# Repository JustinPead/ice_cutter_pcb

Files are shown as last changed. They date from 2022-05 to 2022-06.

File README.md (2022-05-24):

# ice_cutter_pcb
The PCB for the ice cutter project

This is a component for the greater project of an automated Ice cutting rig

The PCB is responsible for providing the power, receiving the power setting (potentiometer) and providing information on the current status (7 Seg and LEDS)
It has an onboard temperature sensor to determine the initial conditions for the ice rig.

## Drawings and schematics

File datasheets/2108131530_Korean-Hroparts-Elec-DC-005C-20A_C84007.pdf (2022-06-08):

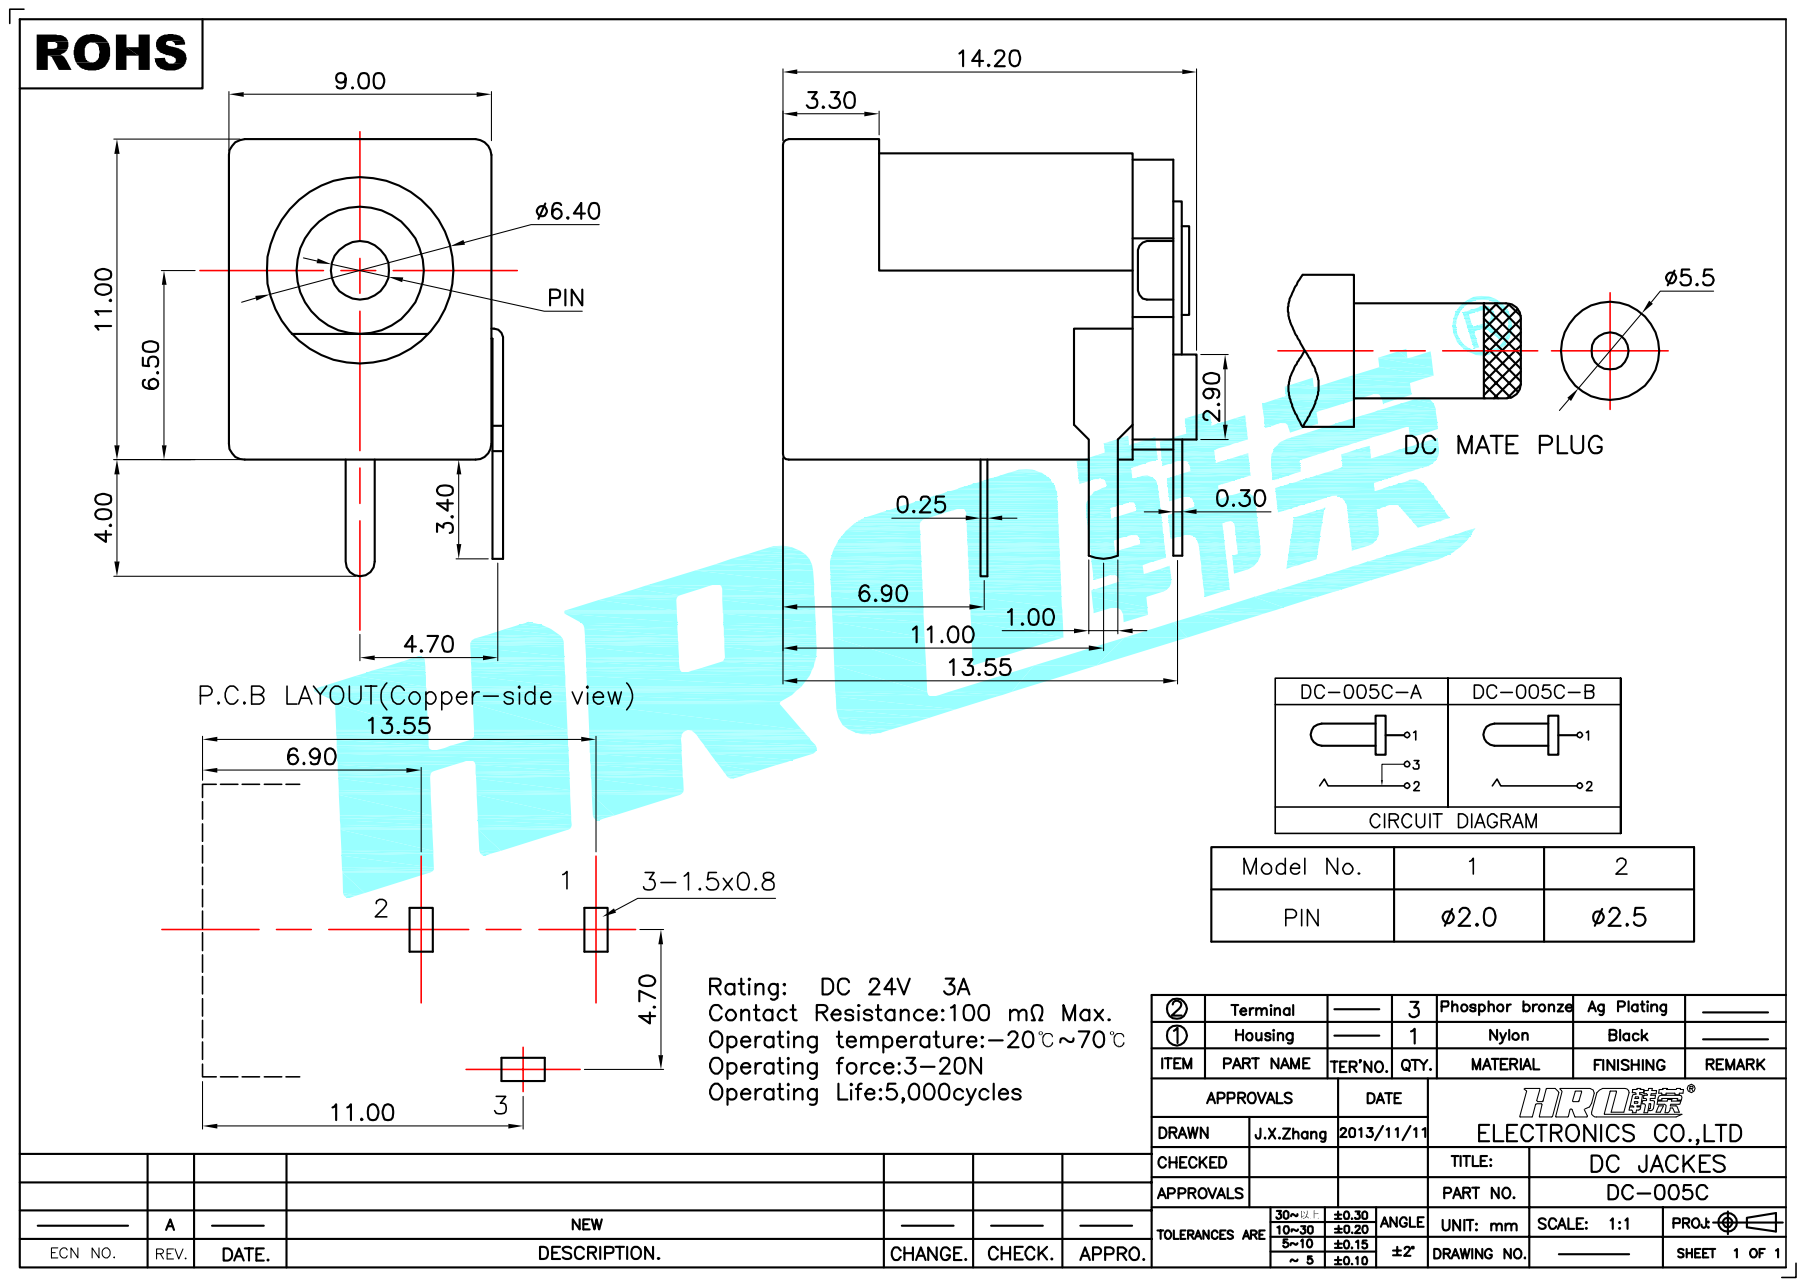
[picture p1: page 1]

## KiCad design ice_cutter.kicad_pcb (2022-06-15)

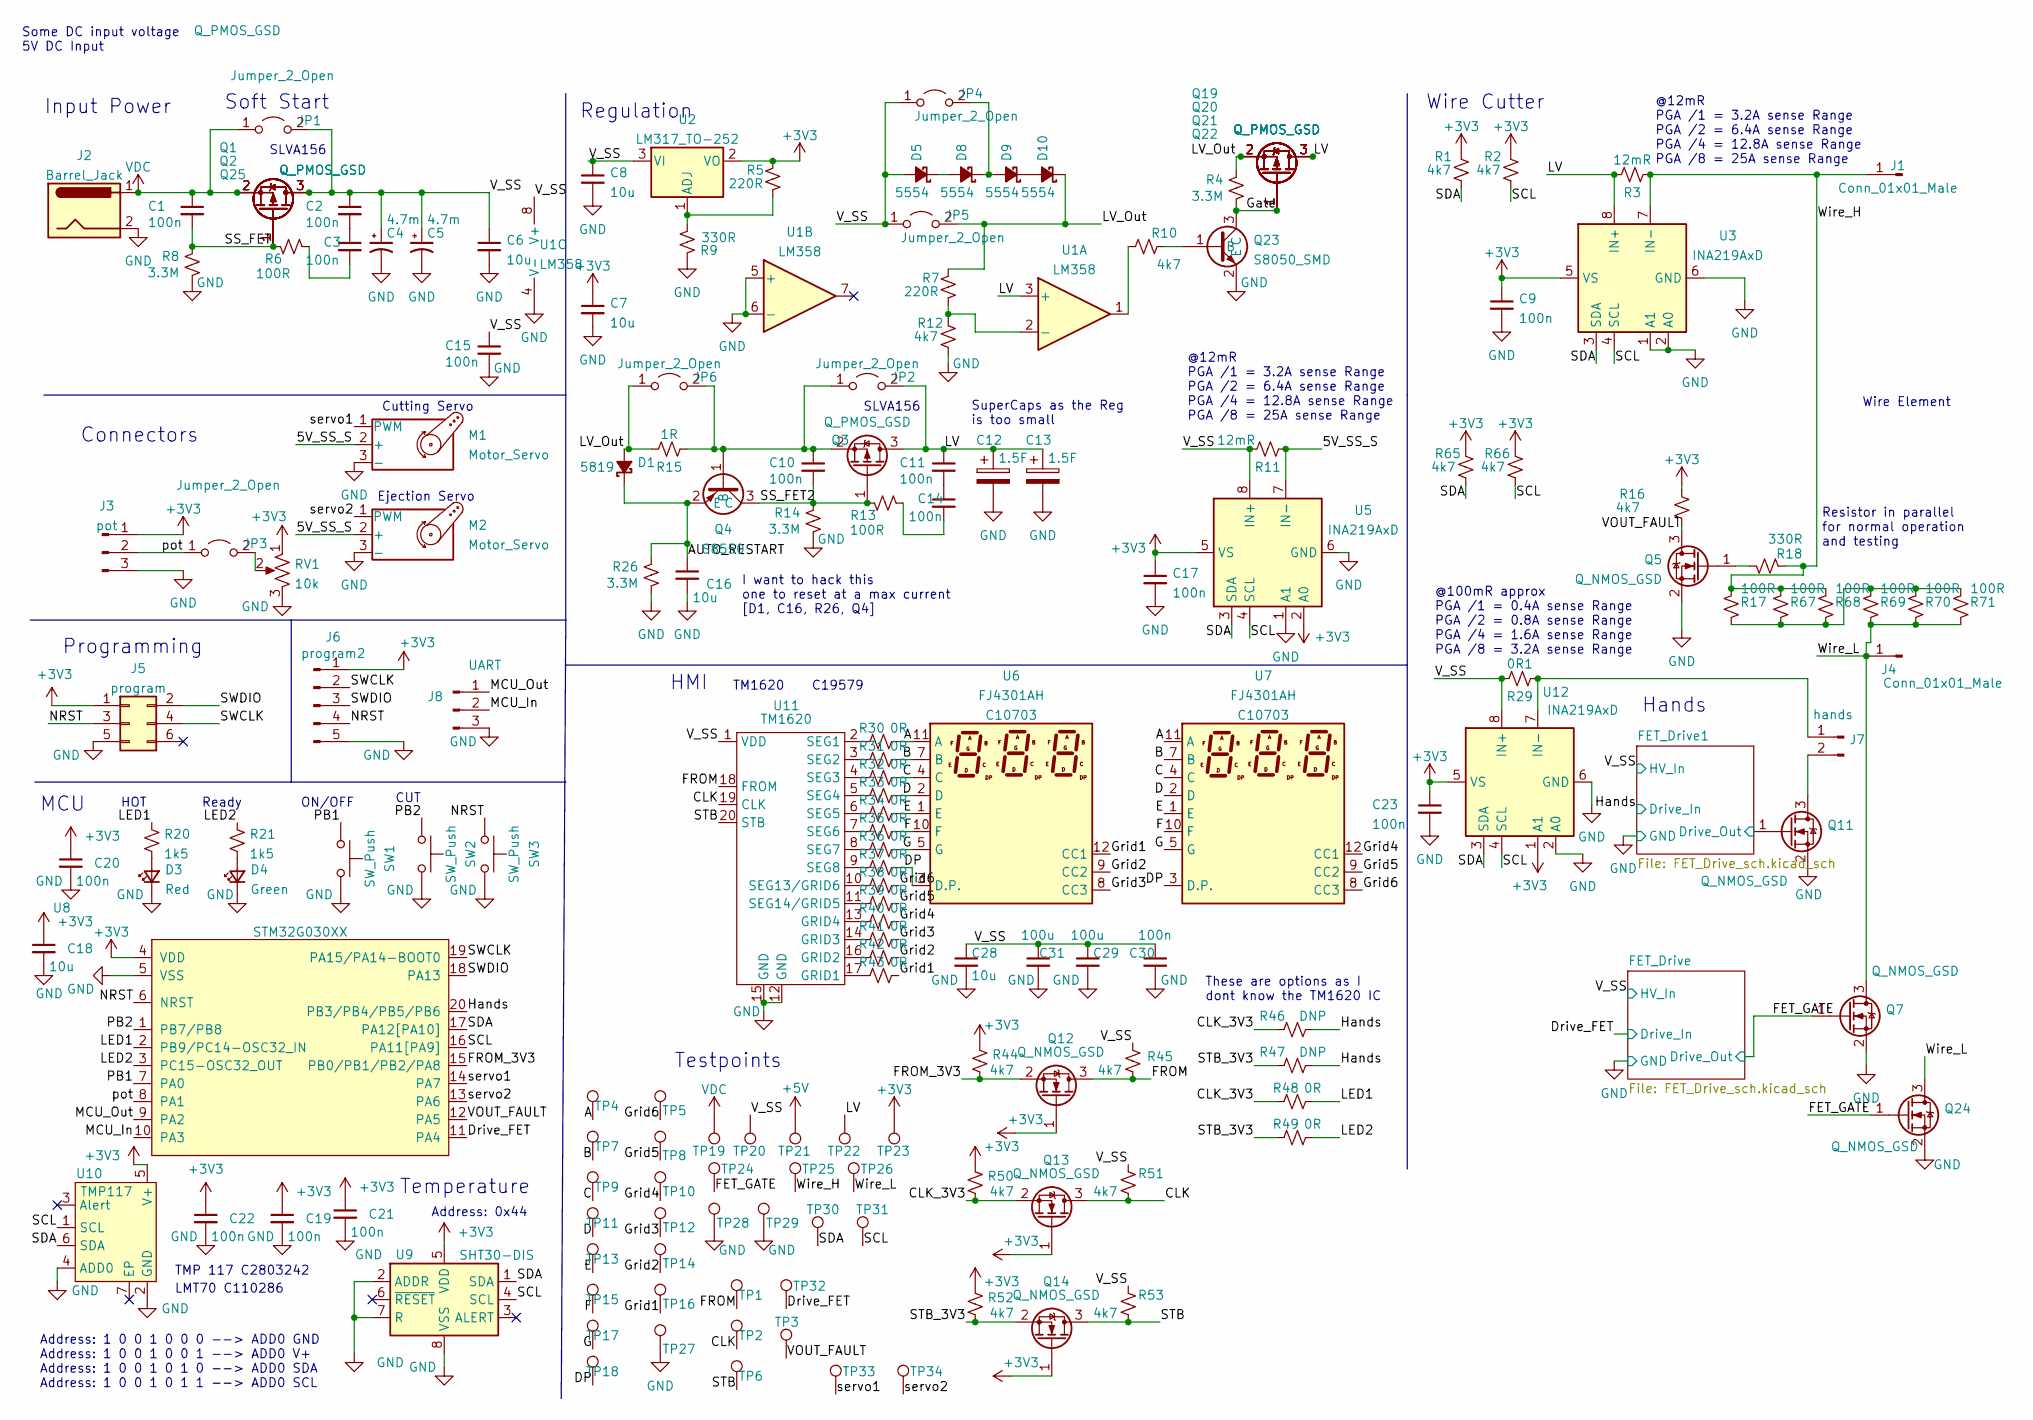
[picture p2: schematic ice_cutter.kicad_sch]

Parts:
C1, C2, C3, C9, C10, C11, C14, C15, C17, C19, C20, C21, C22, C23, C29: 100n; C_0402_1005Metric; LCSC C307331
C4, C5: 4.7m; CP_Radial_D14.0mm_P5.00mm
C6, C7, C8, C16, C18, C28: 10u; C_0603_1608Metric; LCSC C96446
C12, C13: 1.5F; SP-5R5-Z155VY; LCSC C128277
C30, C31: 100u; C_1206_3216Metric_Pad1.33x1.80mm_HandSolder; LCSC C15008
D1: 5819; D_SOD-123; LCSC C963381
D3: Red; D_0603_1608Metric; LCSC C2286
D4: Green; D_0603_1608Metric; LCSC C72043
D5, D8, D9, D10: 5554; D_SMA; LCSC C22452
J1, J4: Conn_01x01_Male; SMD_Pad_15x10
J2: Barrel_Jack; Barrel_Jack_2A_C84007; LCSC C84007
J3: pot; PinHeader_1x03_P2.54mm_Vertical
J5: program; TC2030NL
J6: program2; PinHeader_1x05_P2.54mm_Vertical
J7: hands; PinHeader_1x02_P2.54mm_Vertical
J8: UART; PinHeader_1x03_P2.54mm_Vertical
JP1, JP2, JP3, JP4, JP5, JP6: Jumper_2_Open; SolderJumper-2_P1.3mm_Open_RoundedPad1.0x1.5mm
M1, M2: Motor_Servo; PinHeader_1x03_P2.54mm_Vertical
Q1, Q2, Q3, Q19, Q20, Q21, Q22, Q25: Q_PMOS_GSD; SOT-23; LCSC C15127
Q4: S8550; SOT-23; LCSC C8542
Q5, Q12, Q13, Q14: Q_NMOS_GSD; SOT-23; LCSC C20917
Q7, Q11, Q24: Q_NMOS_GSD; TO-252-2; LCSC C709962
Q23: S8050_SMD; SOT-23; LCSC C2150
R1, R2, R10, R12, R16, R44, R45, R50, R51, R52, R53, R65, R66: 4k7; R_0402_1005Metric; LCSC C25900
R3, R11: 12mR; R_2512_6332Metric; LCSC C323773
R4, R8, R14, R26: 3.3M; R_0402_1005Metric; LCSC C25741
R5, R7: 220R; R_0402_1005Metric; LCSC C25091
R6, R13: 100R; R_0402_1005Metric; LCSC C25076
R9, R18: 330R; R_0402_1005Metric; LCSC C25104
R15: 1R; R_2512_6332Metric; LCSC C11254
R17, R67, R68, R69, R70, R71: 100R; R_1206_3216Metric; LCSC C17901
R20, R21: 1k5; R_0402_1005Metric; LCSC C25867
R29: 0R1; R_1206_3216Metric; LCSC C25334
R30, R31, R32, R33, R34, R35, R36, R37, R38, R39, R40, R41, R42, R43, R48, R49: 0R; R_0402_1005Metric; LCSC C17168
R46, R47: DNP; R_0402_1005Metric; LCSC C17168
RV1: 10k; RK09_THT_Pot_C209770; LCSC C209770
SW1, SW2, SW3: SW_Push; SW_SPST_TL3342; LCSC C318884
TP1, TP2, TP3, TP4, TP5, TP6, TP7, TP8, TP9, TP10, TP11, TP12, TP13, TP14, TP15, TP16, TP17, TP18, TP19, TP20, TP21, TP22, TP23, TP24, TP25, TP26, TP27, TP28, TP29, TP30, TP31, TP32, TP33, TP34: TestPoint; TestPoint_Pad_D2.0mm
U1: LM358; SOIC-8_3.9x4.9mm_P1.27mm
U2: LM317_TO-252; TO-252-2; LCSC C75510
U3, U5, U12: INA219AxD; SOIC-8_3.9x4.9mm_P1.27mm; LCSC C138706
U6, U7: FJ4301AH; 7_Seg_x3; LCSC C10703
U8: STM32G030XX; TSSOP-20_4.4x6.5mm_P0.65mm; LCSC C529330
U9: SHT30-DIS; Sensirion_DFN-8-1EP_2.5x2.5mm_P0.5mm_EP1.1x1.7mm; LCSC C77361
U10: TMP117; WSON-6-1EP_2x2mm_P0.65mm_EP1x1.6mm; LCSC C2803242
U11: TM1620; SOP-20_7.5x12.8mm_P1.27mm; LCSC C19579

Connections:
+3V3: C7.1, C9.1, C17.1, C18.1, C19.1, C20.1, C21.1, C22.1, C23.1, J3.1, J5.1, J6.1, Q12.1 (G), Q13.1 (G), Q14.1 (G), R1.2, R2.2, R5.2, R16.2, R44.1, R50.1, R52.1, R65.2, R66.2, RV1.1, TP23.1, U2.2 (VO), U3.5 (VS), U5.2 (A0), U5.5 (VS), U8.4 (VDD), U9.5 (VDD), U10.5 (V+), U12.1 (A1), U12.5 (VS)
+5V: TP21.1
/5V_SS_S: M1.2 (+), M2.2 (+), R11.2, U5.7 (IN-)
/A: R30.2, TP4.1, U6.11 (A), U7.11 (A)
/AUTO_RESTART: C16.1, D1.1 (K), Q4.2 (E), R26.1
/B: R31.2, TP7.1, U6.7 (B), U7.7 (B)
/C: R32.2, TP9.1, U6.4 (C), U7.4 (C)
/CLK: Q13.3 (D), R51.1, TP2.1, U11.19 (CLK)
/CLK_3V3: Q13.2 (S), R46.1, R48.1, R50.2
/D: R33.2, TP11.1, U6.2 (D), U7.2 (D)
/DP: R37.2, TP18.1, U6.3 (D.P.), U7.3 (D.P.)
/Drive_FET: TP32.1, U8.11 (PA4); also elsewhere on the board
/E: R34.2, TP13.1, U6.1 (E), U7.1 (E)
/F: R35.2, TP15.1, U6.10 (F), U7.10 (F)
/FET_Drive1/Drive_Out: Q11.1 (G); also elsewhere on the board
/FET_GATE: Q7.1 (G), Q24.1 (G), TP24.1; also elsewhere on the board
/FROM: Q12.3 (D), R45.1, TP1.1, U11.18 (FROM)
/FROM_3V3: Q12.2 (S), R44.2, U8.15 (PB0/PB1/PB2/PA8)
/G: R36.2, TP17.1, U6.5 (G), U7.5 (G)
/Gate: Q19.1 (G), Q20.1 (G), Q21.1 (G), Q22.1 (G), Q23.3 (C), R4.2
/Grid1: R43.2, TP16.1, U6.12 (CC1)
/Grid2: R42.2, TP14.1, U6.9 (CC2)
/Grid3: R41.2, TP12.1, U6.8 (CC3)
/Grid4: R40.2, TP10.1, U7.12 (CC1)
/Grid5: R39.2, TP8.1, U7.9 (CC2)
/Grid6: R38.2, TP5.1, U7.8 (CC3)
/Hands: R46.2, R47.2, U8.20 (PB3/PB4/PB5/PB6); also elsewhere on the board
/LED1: R20.1, R48.2, U8.2 (PB9/PC14-OSC32_IN)
/LED2: R21.1, R49.2, U8.3 (PC15-OSC32_OUT)
/LV: C11.1, C12.1, C13.1, JP2.2 (B), Q3.3 (D), Q19.3 (D), Q20.3 (D), Q21.3 (D), Q22.3 (D), R3.1, TP22.1, U1.3 (+), U3.8 (IN+)
/LV_Out: D1.2 (A), D10.1 (K), JP5.2 (B), JP6.1 (A), Q19.2 (S), Q20.2 (S), Q21.2 (S), Q22.2 (S), R4.1, R7.2, R15.1
/MCU_In: J8.2, U8.10 (PA3)
/MCU_Out: J8.1, U8.9 (PA2)
/NRST: J5.3, J6.4, SW3.1, U8.6 (NRST)
/PB1: SW1.1, U8.7 (PA0)
/PB2: SW2.1, U8.1 (PB7/PB8)
/SCL: R2.1, R66.1, TP31.1, U3.4 (SCL), U5.4 (SCL), U8.16 (PA11[PA9]), U9.4 (SCL), U10.1 (SCL), U12.4 (SCL)
/SDA: R1.1, R65.1, TP30.1, U3.3 (SDA), U5.3 (SDA), U8.17 (PA12[PA10]), U9.1 (SDA), U10.6 (SDA), U12.3 (SDA)
/SS_FET: C1.2, Q1.1 (G), Q2.1 (G), Q25.1 (G), R6.1, R8.1
/SS_FET2: C10.2, Q3.1 (G), Q4.3 (C), R13.1, R14.1
/STB: Q14.3 (D), R53.1, TP6.1, U11.20 (STB)
/STB_3V3: Q14.2 (S), R47.1, R49.1, R52.2
/SWCLK: J5.4, J6.2, U8.19 (PA15/PA14-BOOT0)
/SWDIO: J5.2, J6.3, U8.18 (PA13)
/VOUT_FAULT: Q5.3 (D), R16.1, TP3.1, U8.12 (PA5)
/V_SS: C2.1, C4.1, C5.1, C6.1, C8.1, C15.1, C28.1, C29.1, C30.1, C31.1, D5.2 (A), JP1.2 (B), JP4.1 (A), JP5.1 (A), Q1.3 (D), Q2.3 (D), Q25.3 (D), R11.1, R29.1, R45.2, R51.2, R53.2, TP20.1, U1.8 (V+), U2.3 (VI), U5.8 (IN+), U11.1 (VDD), U12.8 (IN+); also elsewhere on the board
/Wire_H: J1.1, R3.2, R17.1, R18.1, R67.1, R68.1, TP25.1, U3.7 (IN-)
/Wire_L: J4.1, Q7.3 (D), Q24.3 (D), R69.2, R70.2, R71.2, TP26.1
/pot: J3.2, JP3.1 (A), U8.8 (PA1)
/servo1: M1.1 (PWM), TP33.1, U8.14 (PA7)
/servo2: M2.1 (PWM), TP34.1, U8.13 (PA6)
GND: C4.2, C5.2, C6.2, C7.2, C8.2, C9.2, C12.2, C13.2, C15.2, C16.2, C17.2, C18.2, C19.2, C20.2, C21.2, C22.2, C23.2, C28.2, C29.2, C30.2, C31.2, D3.1 (K), D4.1 (K), J2.2, J3.3, J5.5, J6.5, J8.3, M1.3 (-), M2.3 (-), Q5.2 (S), Q7.2 (S), Q11.2 (S), Q23.2 (E), Q24.2 (S), R8.2, R9.1, R12.1, R14.2, R26.2, RV1.3, SW1.2, SW2.2, SW3.2, TP27.1, TP28.1, TP29.1, U1.4 (V-), U1.5 (+), U1.6 (-), U3.1 (A1), U3.2 (A0), U3.6 (GND), U5.1 (A1), U5.6 (GND), U8.5 (VSS), U9.2 (ADDR), U9.7 (R), U9.8 (VSS), U9.9 (VSS), U10.2 (GND), U10.4 (ADD0), U11.12 (GND), U11.15 (GND), U12.2 (A0), U12.6 (GND); also elsewhere on the board
unnamed: C2.2, C3.1
unnamed: C3.2, R6.2
unnamed: C10.1, JP2.1 (A), JP6.2 (B), Q3.2 (S), Q4.1 (B), R15.2
unnamed: C11.2, C14.1
unnamed: C14.2, R13.2
unnamed: D3.2 (A), R20.2
unnamed: D4.2 (A), R21.2
unnamed: D5.1 (K), D8.2 (A)
unnamed: D8.1 (K), D9.2 (A), JP4.2 (B)
unnamed: D9.1 (K), D10.2 (A)
unnamed: J7.1, R29.2, U12.7 (IN-)
unnamed: J7.2, Q11.3 (D)
unnamed: JP3.2 (B), RV1.2
unnamed: Q5.1 (G), R18.2
unnamed: Q23.1 (B), R10.1
unnamed: R5.1, R9.2, U2.1 (ADJ)
unnamed: R10.2, U1.1
unnamed: R7.1, R12.2, U1.2 (-)
unnamed: R30.1, U11.2 (SEG1)
unnamed: R31.1, U11.3 (SEG2)
unnamed: R32.1, U11.4 (SEG3)
unnamed: R33.1, U11.5 (SEG4)
unnamed: R34.1, U11.6 (SEG5)
unnamed: R35.1, U11.7 (SEG6)
unnamed: R36.1, U11.8 (SEG7)
unnamed: R37.1, U11.9 (SEG8)
unnamed: R38.1, U11.10 (SEG13/GRID6)
unnamed: R39.1, U11.11 (SEG14/GRID5)
unnamed: R40.1, U11.13 (GRID4)
unnamed: R41.1, U11.14 (GRID3)
unnamed: R42.1, U11.16 (GRID2)
unnamed: R43.1, U11.17 (GRID1)
unnamed: R17.2, R67.2, R68.2, R69.1, R70.1, R71.1
VDC: C1.1, J2.1, JP1.1 (A), Q1.2 (S), Q2.2 (S), Q25.2 (S), TP19.1

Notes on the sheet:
ON/OFF
Ejection Servo
Programming
Regulation
TM1620 C19579
SLVA156
Connectors
Resistor in parallel for normal operation and testing
CUT
Address: 0x44
LMT70 C110286
HMI
TMP 117 C2803242
Ready
Some DC input voltage 5V DC Input
These are options as I dont know the TM1620 IC
I want to hack this one to reset at a max current [D1, C16, R26, Q4]
Hands
MCU
SuperCaps as the Reg is too small
@12mR PGA /1 = 3.2A sense Range PGA /2 = 6.4A sense Range PGA /4 = 12.8A sense Range PGA /8 = 25A sense Range
Input Power
Soft Start
HOT
Cutting Servo
Temperature
Address: 1 0 0 1 0 0 0 --> ADD0 GND Address: 1 0 0 1 0 0 1 --> ADD0 V+ Address: 1 0 0 1 0 1 0 --> ADD0 SDA Address: 1 0 0 1 0 1 1 --> ADD0 SCL
Wire Element
Testpoints
Wire Cutter
@100mR approx PGA /1 = 0.4A sense Range PGA /2 = 0.8A sense Range PGA /4 = 1.6A sense Range PGA /8 = 3.2A sense Range

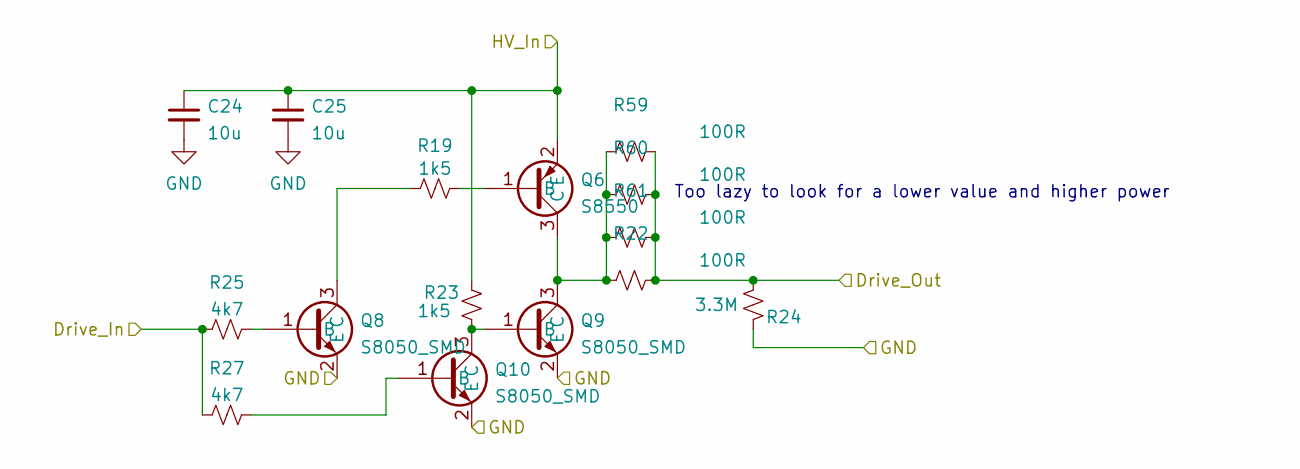
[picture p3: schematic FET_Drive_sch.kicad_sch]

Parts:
C24, C25: 10u; C_0603_1608Metric; LCSC C96446
Q6: S8550; SOT-23; LCSC C8542
Q8, Q9, Q10: S8050_SMD; SOT-23; LCSC C2150
R19, R23: 1k5; R_0402_1005Metric; LCSC C25867
R22, R59, R60, R61: 100R; R_0402_1005Metric; LCSC C25076
R24: 3.3M; R_0402_1005Metric; LCSC C25741
R25, R27: 4k7; R_0402_1005Metric; LCSC C25900

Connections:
/Drive_FET: R25.1, R27.1; also elsewhere on the board
/FET_GATE: R22.2, R24.1, R59.2, R60.2, R61.2; also elsewhere on the board
/V_SS: C24.1, C25.1, Q6.2 (E), R23.2; also elsewhere on the board
GND: C24.2, C25.2, Q8.2 (E), Q9.2 (E), Q10.2 (E), R24.2; also elsewhere on the board
unnamed: Q6.1 (B), R19.2
unnamed: Q6.3 (C), Q9.3 (C), R22.1, R59.1, R60.1, R61.1
unnamed: Q8.1 (B), R25.2
unnamed: Q8.3 (C), R19.1
unnamed: Q10.1 (B), R27.2
unnamed: Q9.1 (B), Q10.3 (C), R23.1

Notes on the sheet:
Too lazy to look for a lower value and higher power

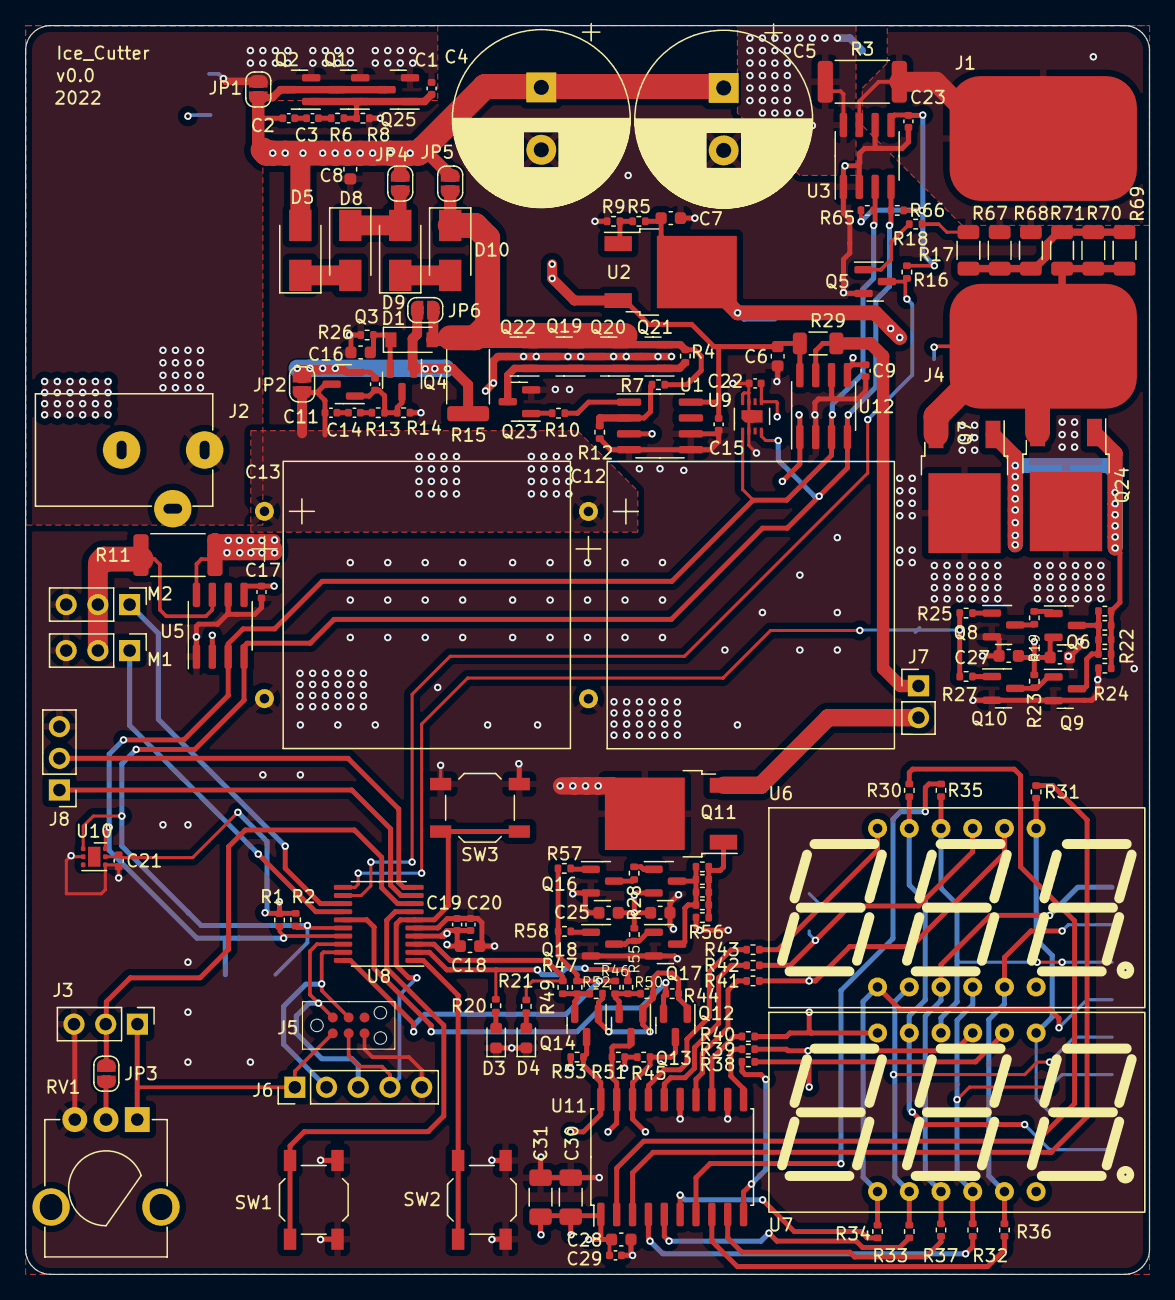
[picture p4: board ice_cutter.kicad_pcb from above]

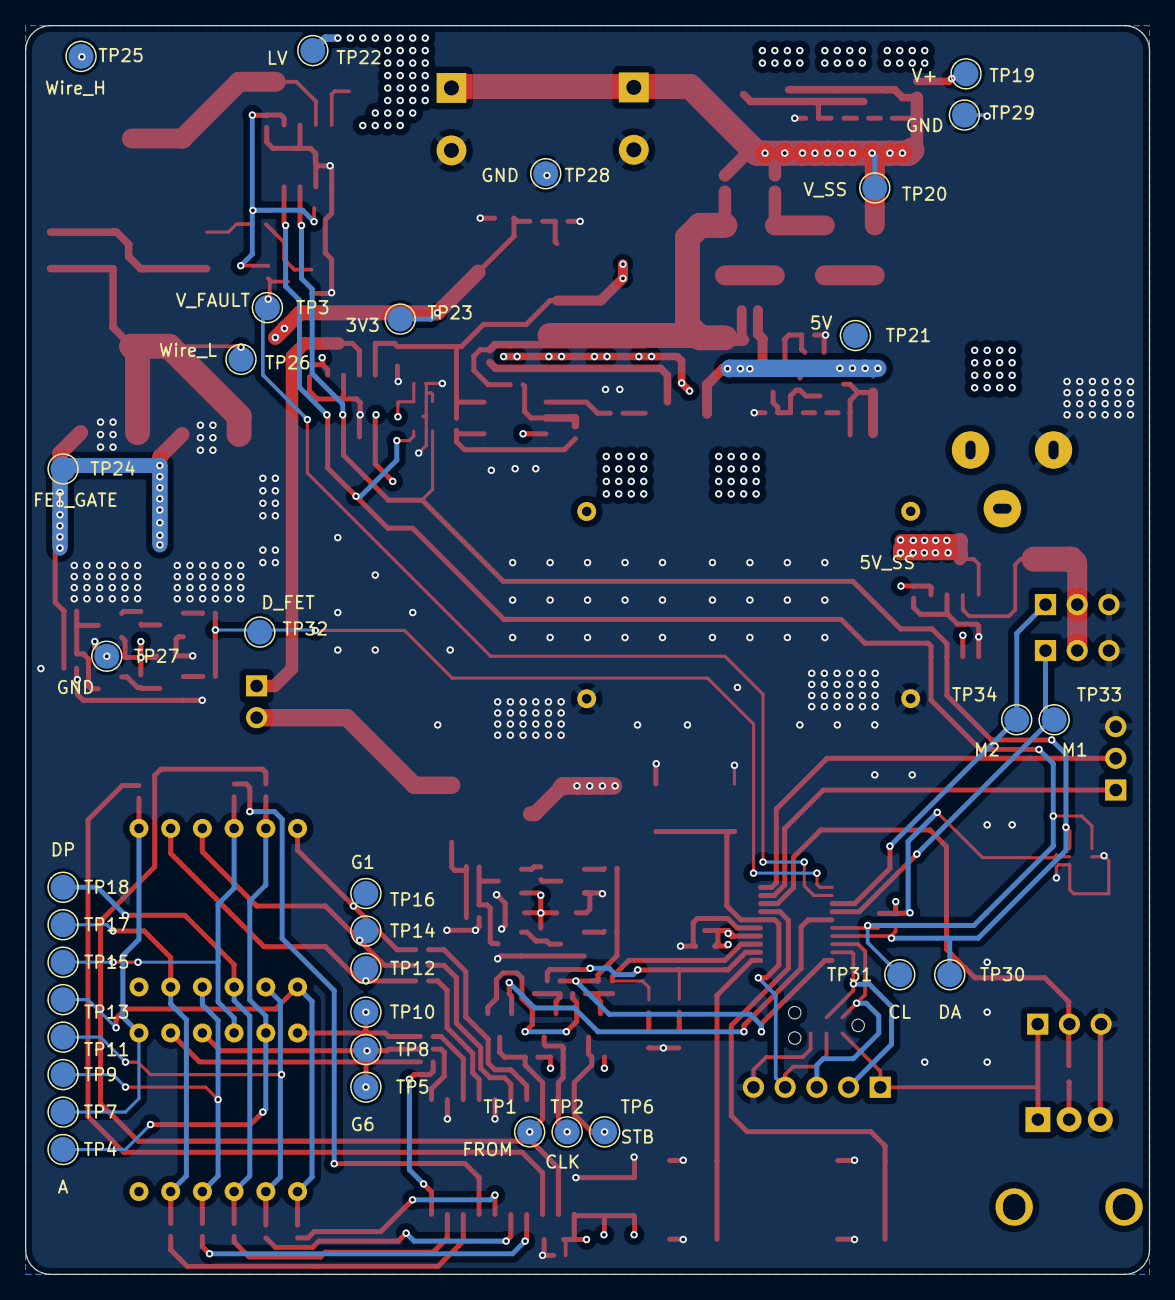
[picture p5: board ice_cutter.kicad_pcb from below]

Board: 4 copper layers, 90.0 x 100.0 mm, 199 parts (34 on the bottom side), 97 nets.

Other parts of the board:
C26, C27: 10u; C_0603_1608Metric
Q15: S8550; SOT-23
Q16, Q17, Q18: S8050_SMD; SOT-23
R28, R55: 1k5; R_0402_1005Metric
R54, R62, R63, R64: 100R; R_0402_1005Metric
R56: 3.3M; R_0402_1005Metric
R57, R58: 4k7; R_0402_1005Metric

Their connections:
/FET_Drive1/Drive_Out: R54.2, R56.1, R62.2, R63.2, R64.2; also elsewhere on the board
/Hands: R57.1, R58.1; also elsewhere on the board
/V_SS: C26.1, C27.1, Q15.2 (E), R55.2; also elsewhere on the board
GND: C26.2, C27.2, Q16.2 (E), Q17.2 (E), Q18.2 (E), R56.2; also elsewhere on the board
unnamed: Q15.1 (B), R28.2
unnamed: Q15.3 (C), Q17.3 (C), R54.1, R62.1, R63.1, R64.1
unnamed: Q16.1 (B), R57.2
unnamed: Q16.3 (C), R28.1
unnamed: Q17.1 (B), Q18.3 (C), R55.1
unnamed: Q18.1 (B), R58.2

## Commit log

2022-05-24 tracking datasheets, and schematic improvements
    [ice_cutter.kicad_sch]
2022-05-24 inclusion of motors and schematic improvements
    [ice_cutter.kicad_sch]
2022-05-30 Added TM1620 symbol to library(LED drive control)
    [ice_cutter.kicad_sch]
2022-06-08 Changes in schematic, added Soft starts everywhere...
    [ice_cutter.kicad_sch]
2022-06-08 added barrel jack and super caps
    [ice_cutter.kicad_sch]
2022-06-09 added some TP and some 0R resistors and a program header for simple programming
    [ice_cutter.kicad_sch]
2022-06-09 added more TP
    [ice_cutter.kicad_sch]
2022-06-10 Think I have finished the schematic
    [FET_Drive_sch.kicad_sch, ice_cutter.kicad_sch]
2022-06-10 Some layout done, no wiring yet
    [FET_Drive_sch.kicad_sch, ice_cutter.kicad_pcb]
2022-06-11 moree wiring done, shrank board slightly. Unsure whether 4 layer is necessary
    [FET_Drive_sch.kicad_sch, ice_cutter.kicad_pcb, ice_cutter.kicad_sch]
2022-06-11 more wiring done, shrank board slightly. Unsure whether 4 layer is necessary - HADNT saved PCB
    [ice_cutter.kicad_pcb]
2022-06-11 got lazy, went 4 layer. Some of layer 3 done. progressing. Mainly committing for board chronological how to sake. Added Caps on the TM1620
    [FET_Drive_sch.kicad_sch, ice_cutter.kicad_pcb, ice_cutter.kicad_sch]
2022-06-11 more PCB progress
    [ice_cutter.kicad_pcb]
2022-06-11 finished v0 I hope
    [ice_cutter.kicad_pcb]
2022-06-11 additional save
    [ice_cutter.kicad_pcb]
2022-06-12 improved schematic and changed the shunt resistors
    [ice_cutter.kicad_pcb, ice_cutter.kicad_sch]
2022-06-12 Neatened the schematic
    [FET_Drive_sch.kicad_sch, ice_cutter.kicad_sch]
2022-06-14 modified the system to operate on 5V - bypassed all regs and changed the BIG FET to a lower threshold V
    [ice_cutter.kicad_pcb, ice_cutter.kicad_sch]
2022-06-14 major schematic changes, 5V is now the highest voltage, added more FETs for Wire conduction, more for SS, opamp for current hack, removed Regs, XT60 and significantly changed wiring and R values for 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
    [FET_Drive_sch.kicad_sch, ice_cutter.kicad_pcb, ice_cutter.kicad_sch]
2022-06-15 more mods, taking it to a solution. Mostly on layer 3 and power management
    [ice_cutter.kicad_pcb, ice_cutter.kicad_sch]
2022-06-15 potential new version. Still to do Silkscreen and resistor value confirmations
    [FET_Drive_sch.kicad_sch, ice_cutter.kicad_pcb, ice_cutter.kicad_sch]
2022-06-15 hadnt saved... this is the last commit message
    [FET_Drive_sch.kicad_sch, ice_cutter.kicad_sch]
2022-06-15 5V version - I hope it works
    [ice_cutter.kicad_pcb, ice_cutter.kicad_sch]
2022-06-15 havent saved again...
    [FET_Drive_sch.kicad_sch, ice_cutter.kicad_pcb]
